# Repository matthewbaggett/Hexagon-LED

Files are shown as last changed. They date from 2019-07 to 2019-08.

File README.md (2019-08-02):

# Hexagon LED

## Objective:

Build a small, inexpensive hexagonal lighting PCB with an inexpensive microcontroller that can communicate using slow-speed software serial
 with the other attached nodes and to an optionally fitted ESP8266 ESP-01 module which will designate itself the "host", 
 and populate out colour information from the center.
 
A serial mesh of communication between each interlinked hexagonal node.

A REST service running on the ESP sat on the users Wifi allowing for colour information to be pushed from an app or script.

## Render
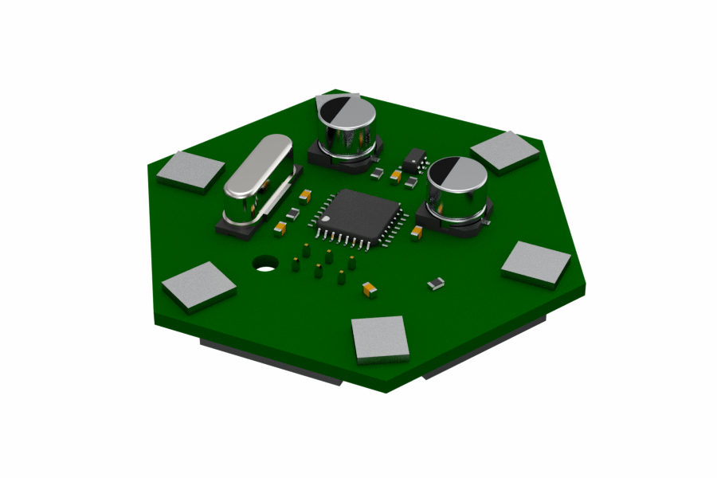
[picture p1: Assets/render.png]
Render


## Board
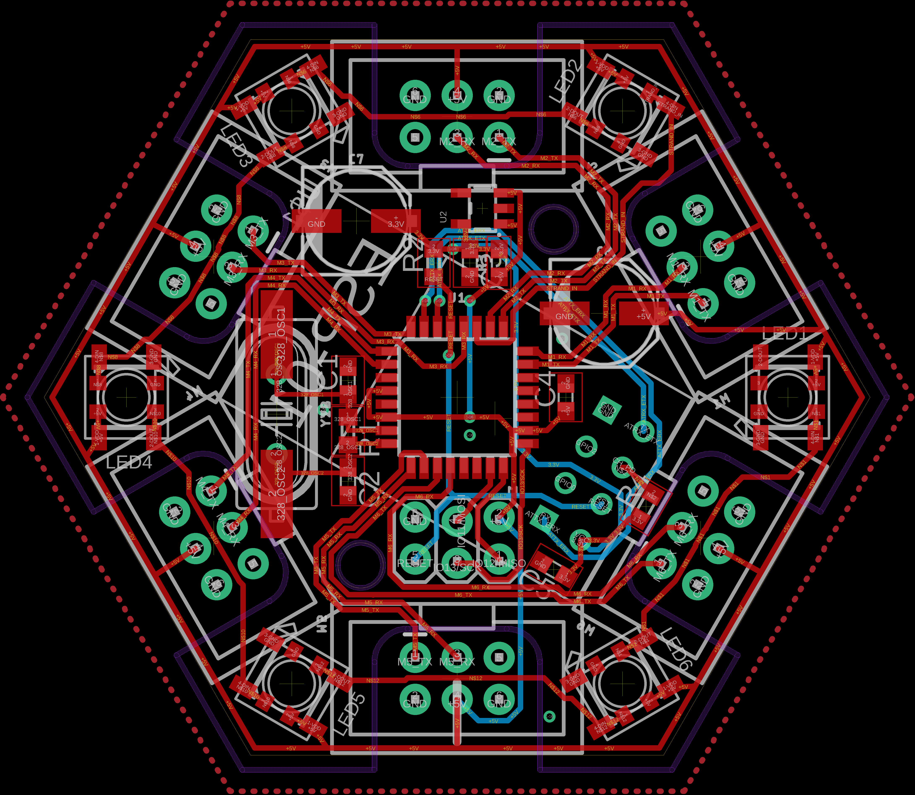
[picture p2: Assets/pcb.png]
Board


Not shown: Groundplane fill. Represented by area inside red dashed octagon

Purple outline: Lasercut rear plastic panel to insert into the back of a 3d printed housing.

Illustration shows shielded 3x2 keyed connectors, not necessarily fitted.

## Schematic

### Microcontroller
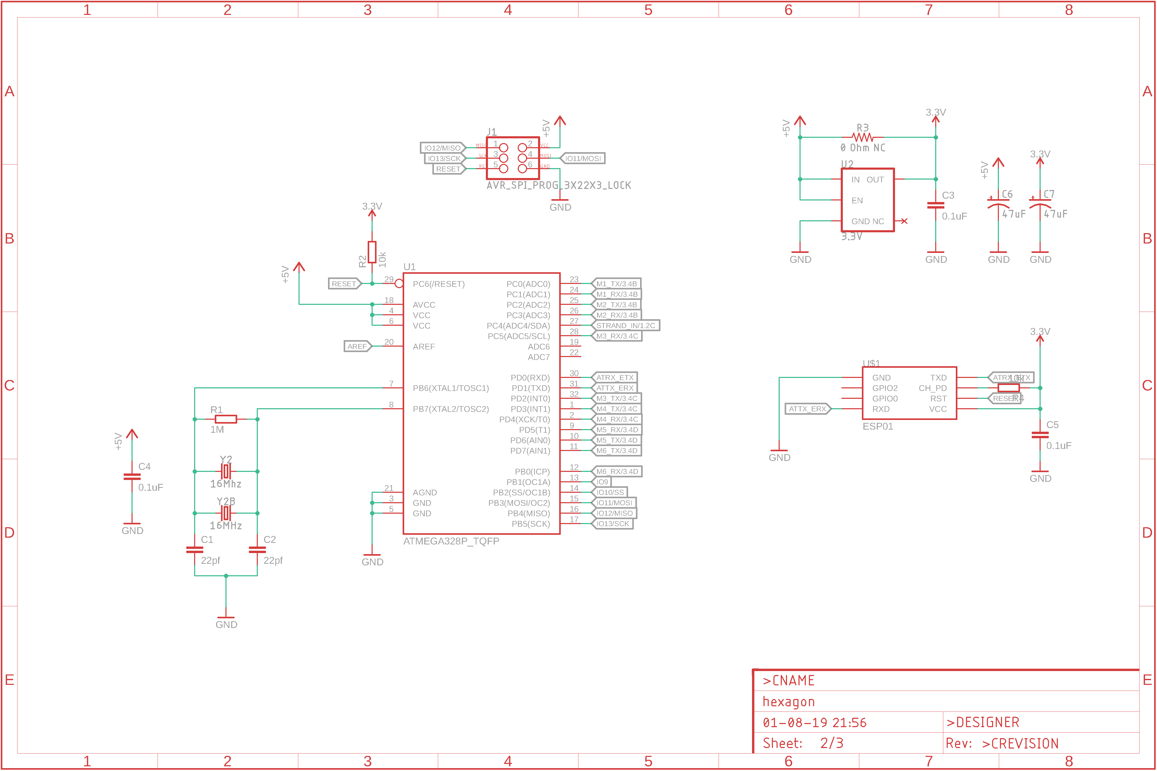
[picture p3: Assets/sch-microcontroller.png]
Microcontroller


### LEDs
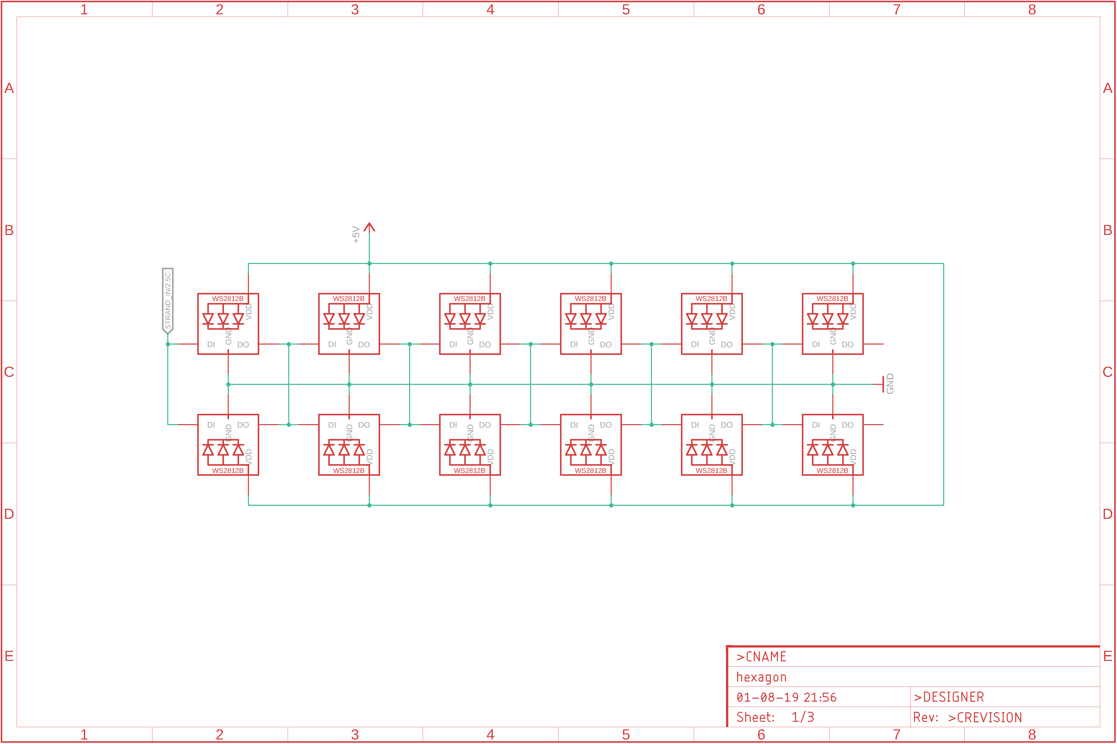
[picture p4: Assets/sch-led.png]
Addressable LEDs


### Interconnects
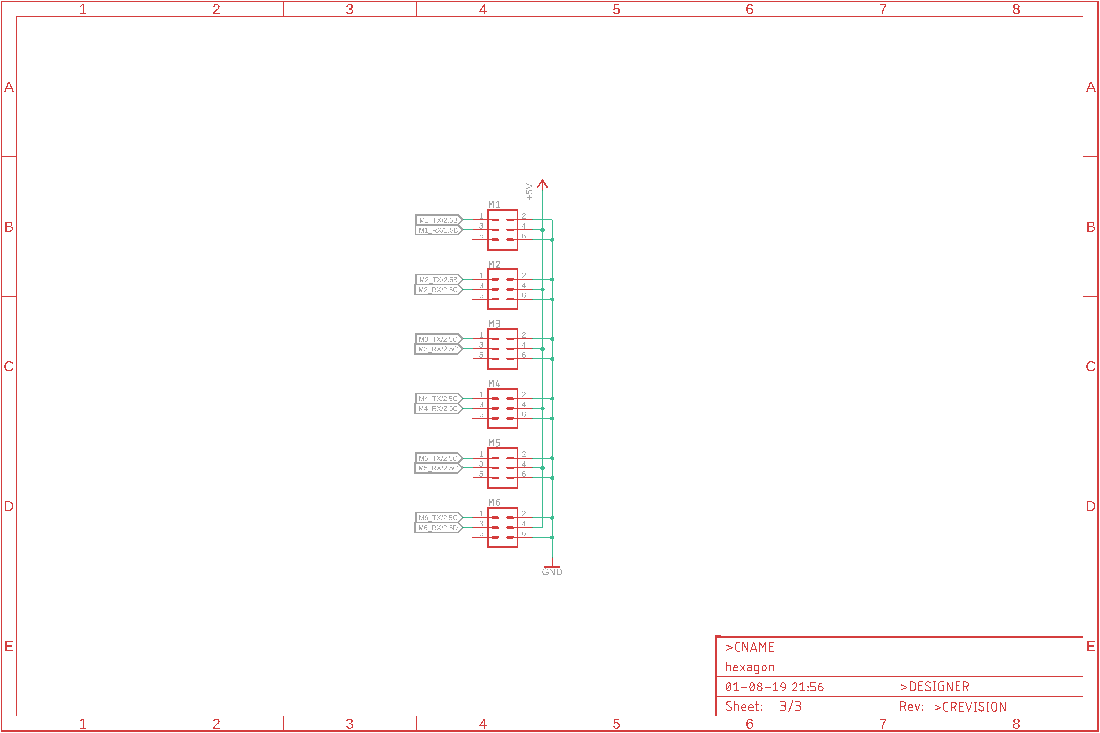
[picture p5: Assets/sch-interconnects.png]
Interconnects


## License
This project is licensed under the The TAPR Open Hardware License.

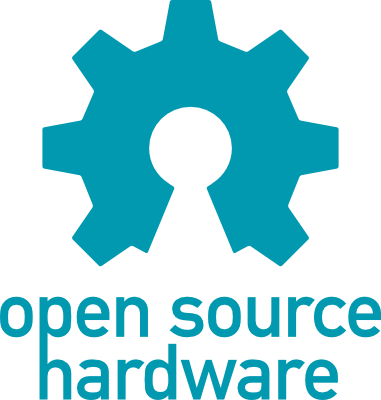
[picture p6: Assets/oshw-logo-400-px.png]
OSHW logo


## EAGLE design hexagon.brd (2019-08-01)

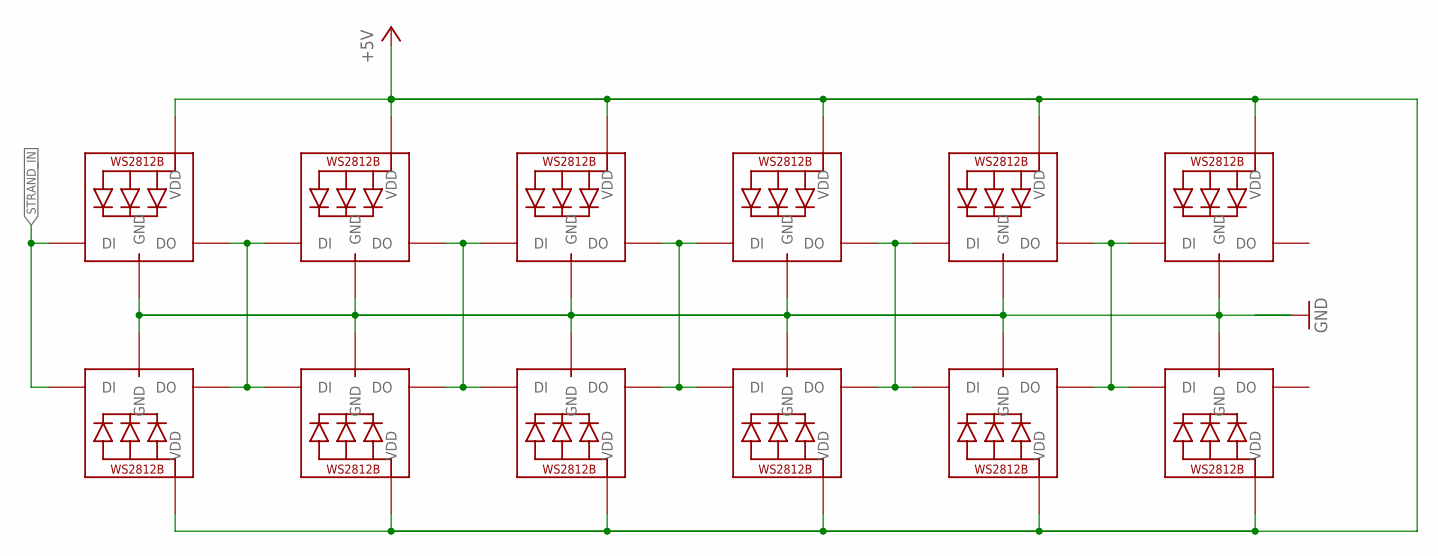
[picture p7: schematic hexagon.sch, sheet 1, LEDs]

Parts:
LED1, LED2, LED3, LED4, LED5, LED6: WS2812B5050; WS2812B
LED7, LED8, LED9, LED10, LED11, LED12: WS2812B3535; LED3535

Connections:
+5V: LED1.1-VDD (VDD), LED2.1-VDD (VDD), LED3.1-VDD (VDD), LED4.1-VDD (VDD), LED5.1-VDD (VDD), LED6.1-VDD (VDD), LED7.2 (VDD), LED8.2 (VDD), LED9.2 (VDD), LED10.2 (VDD), LED11.2 (VDD), LED12.2 (VDD); also elsewhere on the board
GND: LED1.3-GND (GND), LED2.3-GND (GND), LED3.3-GND (GND), LED4.3-GND (GND), LED5.3-GND (GND), LED6.3-GND (GND), LED7.4 (GND), LED8.4 (GND), LED9.4 (GND), LED10.4 (GND), LED11.4 (GND), LED12.4 (GND); also elsewhere on the board
unnamed: LED1.4-DIN (DI), LED6.2-DOUT (DO), LED7.1 (DI), LED12.3 (DO)
unnamed: LED2.2-DOUT (DO), LED3.4-DIN (DI), LED8.3 (DO), LED9.1 (DI)
unnamed: LED3.2-DOUT (DO), LED4.4-DIN (DI), LED9.3 (DO), LED10.1 (DI)
unnamed: LED4.2-DOUT (DO), LED5.4-DIN (DI), LED10.3 (DO), LED11.1 (DI)
unnamed: LED5.2-DOUT (DO), LED6.4-DIN (DI), LED11.3 (DO), LED12.1 (DI)
STRAND_IN: LED2.4-DIN (DI), LED8.1 (DI); also elsewhere on the board

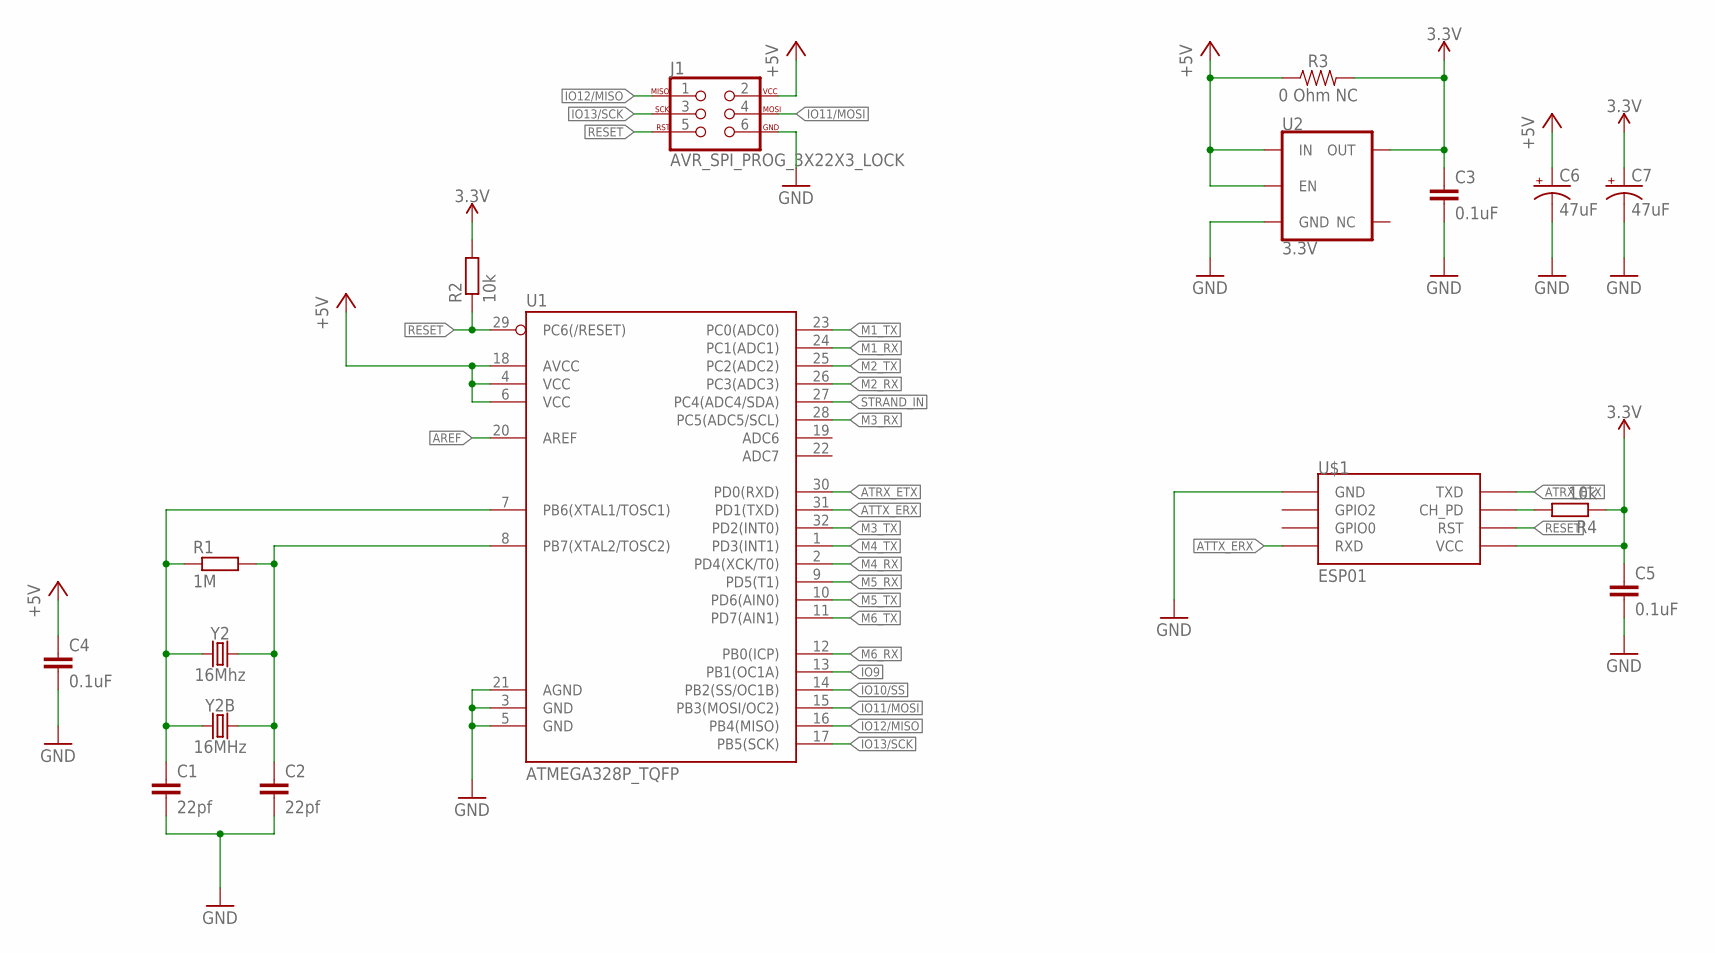
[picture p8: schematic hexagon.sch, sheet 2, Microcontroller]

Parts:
C1, C2: 22pf; C0603
C3, C4, C5: 0.1uF; C0603
C6, C7: 47uF; PANASONIC_D
J1: AVR_SPI_PROG_3X22X3_LOCK; 2X3_LOCK
R1: 1M; R0603
R2, R4: 10k; R0603
R3: 0 Ohm NC; 0603
U1: ATMEGA328P_TQFP; TQFP32-08
U2: 3.3V; SOT23-5
U$1: ESP01
Y2: 16Mhz; HC49UP
Y2B: 16MHz; HC49U

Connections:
3.3V: C3.1, C5.1, C7.+, R2.2, R3.2, R4.1, U2.5 (OUT), U$1.VCC
328_OSC1: C1.1, R1.1, U1.7 (PB6(XTAL1/TOSC1)), Y2.1, Y2B.1
328_OSC2: C2.1, R1.2, U1.8 (PB7(XTAL2/TOSC2)), Y2.2, Y2B.2
+5V: C4.1, C6.+, J1.2, R3.1, U1.4 (VCC), U1.6 (VCC), U1.18 (AVCC), U2.1 (IN), U2.3 (EN); also elsewhere on the board
AREF: U1.20 (AREF)
ATRX_ETX: U1.30 (PD0(RXD)), U$1.TX (TXD)
ATTX_ERX: U1.31 (PD1(TXD)), U$1.RX (RXD)
GND: C1.2, C2.2, C3.2, C4.2, C5.2, C6.-, C7.-, J1.6, U1.3 (GND), U1.5 (GND), U1.21 (AGND), U2.2 (GND), U$1.GND; also elsewhere on the board
IO9: U1.13 (PB1(OC1A))
IO10/SS: U1.14 (PB2(SS/OC1B))
IO11/MOSI: J1.4, U1.15 (PB3(MOSI/OC2))
IO12/MISO: J1.1, U1.16 (PB4(MISO))
IO13/SCK: J1.3, U1.17 (PB5(SCK))
M1_RX: U1.24 (PC1(ADC1)); also elsewhere on the board
M1_TX: U1.23 (PC0(ADC0)); also elsewhere on the board
M2_RX: U1.26 (PC3(ADC3)); also elsewhere on the board
M2_TX: U1.25 (PC2(ADC2)); also elsewhere on the board
M3_RX: U1.28 (PC5(ADC5/SCL)); also elsewhere on the board
M3_TX: U1.32 (PD2(INT0)); also elsewhere on the board
M4_RX: U1.2 (PD4(XCK/T0)); also elsewhere on the board
M4_TX: U1.1 (PD3(INT1)); also elsewhere on the board
M5_RX: U1.9 (PD5(T1)); also elsewhere on the board
M5_TX: U1.10 (PD6(AIN0)); also elsewhere on the board
M6_RX: U1.12 (PB0(ICP)); also elsewhere on the board
M6_TX: U1.11 (PD7(AIN1)); also elsewhere on the board
unnamed: R4.2, U$1.CH_PD
RESET: J1.5, R2.1, U1.29 (PC6(/RESET)), U$1.RST
STRAND_IN: U1.27 (PC4(ADC4/SDA)); also elsewhere on the board

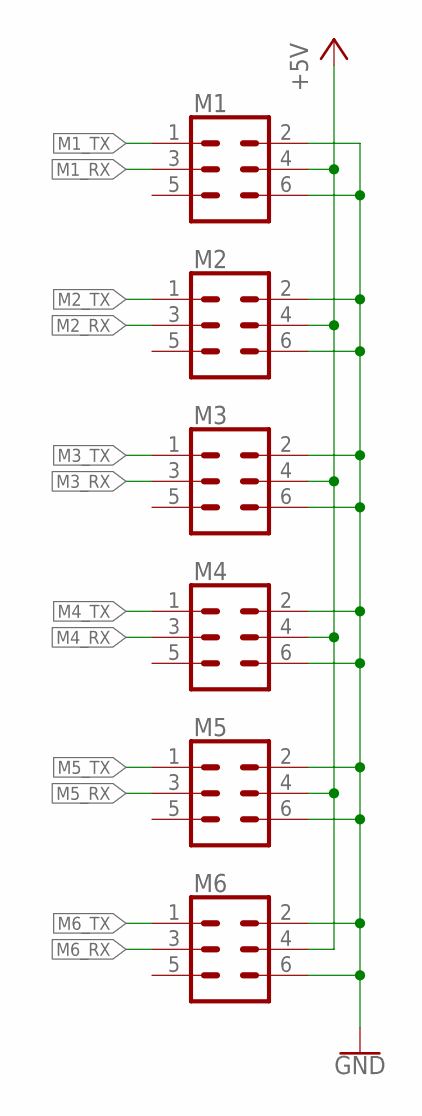
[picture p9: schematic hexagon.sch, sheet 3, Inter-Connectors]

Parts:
M1, M2, M3, M4, M5, M6: CONN_03X2SHROUD; 2X3-SHROUDED

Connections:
+5V: M1.4, M2.4, M3.4, M4.4, M5.4, M6.4; also elsewhere on the board
GND: M1.2, M1.6, M2.2, M2.6, M3.2, M3.6, M4.2, M4.6, M5.2, M5.6, M6.2, M6.6; also elsewhere on the board
M1_RX: M1.3; also elsewhere on the board
M1_TX: M1.1; also elsewhere on the board
M2_RX: M2.3; also elsewhere on the board
M2_TX: M2.1; also elsewhere on the board
M3_RX: M3.3; also elsewhere on the board
M3_TX: M3.1; also elsewhere on the board
M4_RX: M4.3; also elsewhere on the board
M4_TX: M4.1; also elsewhere on the board
M5_RX: M5.3; also elsewhere on the board
M5_TX: M5.1; also elsewhere on the board
M6_RX: M6.3; also elsewhere on the board
M6_TX: M6.1; also elsewhere on the board

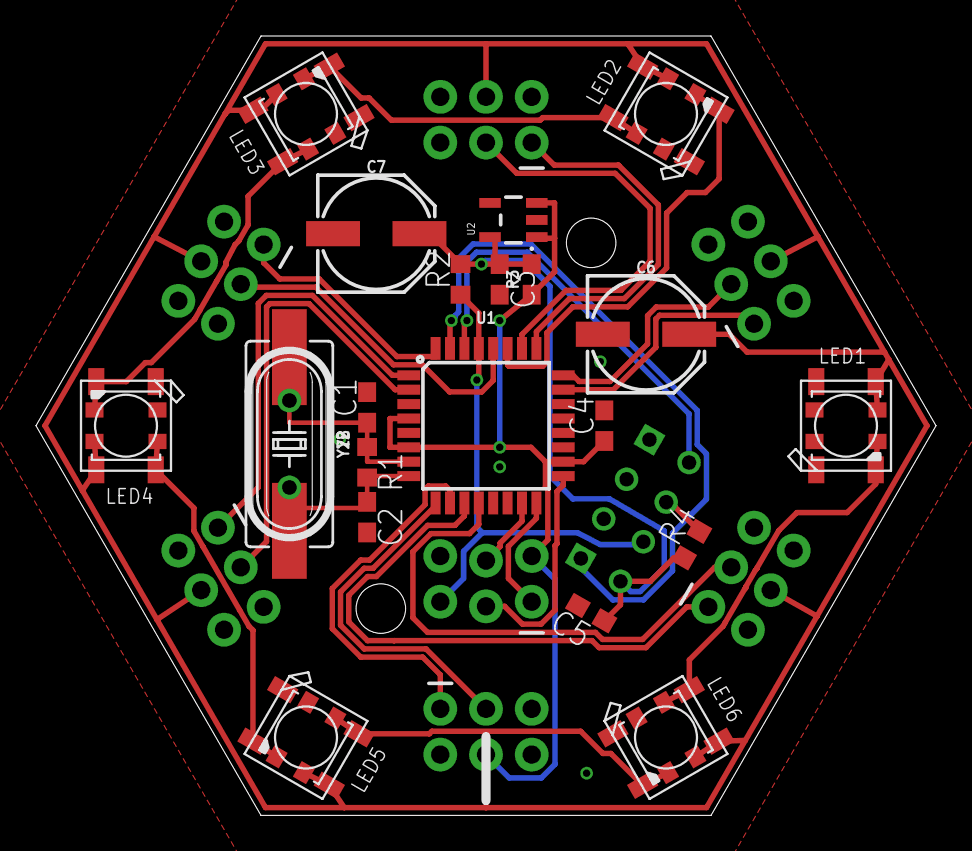
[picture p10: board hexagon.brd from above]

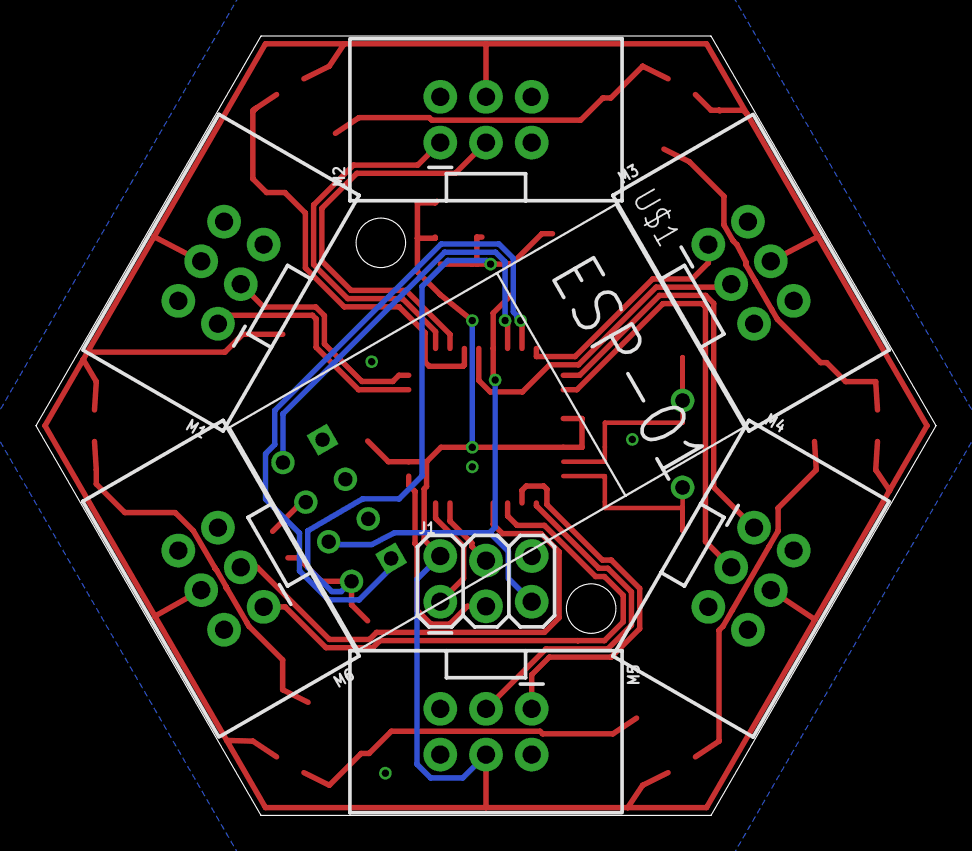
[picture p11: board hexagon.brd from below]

Board: 2 copper layers, 50.0 x 43.3 mm, 35 parts (8 on the bottom side), 30 nets.

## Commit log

2019-07-15 Initial layout
    [hexagon.brd, hexagon.sch]
2019-07-16 Continuing to work out the layout kinks. Added ESP.
    [hexagon.brd, hexagon.sch, interconnect.brd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]
2019-07-17 Fix continuity of bHousing
    [hexagon.brd]
2019-08-01 Gussy up with a readme and some renders
    [hexagon.brd, hexagon.sch, interconnect.brd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]

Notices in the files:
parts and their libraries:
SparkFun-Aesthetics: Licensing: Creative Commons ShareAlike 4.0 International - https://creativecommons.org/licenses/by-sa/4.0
